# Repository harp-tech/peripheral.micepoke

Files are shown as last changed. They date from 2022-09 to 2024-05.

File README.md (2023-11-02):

# Peripheral - Mice Poke

## General description

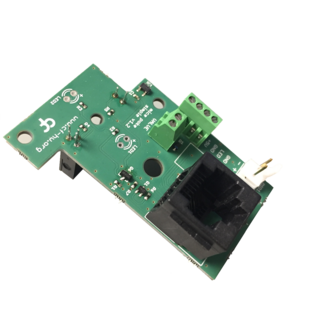
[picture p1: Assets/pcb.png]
"Mice Poke PCB"


----

[//]: # (Tables can be generated using: https://www.tablesgenerator.com/markdown_tables)

## Hardware compatibility

| Peripheral HW Version 	| Board 	 | Board HW Version 	| Notes 	|
|---	|---	 |---	|---	|
| **1.3** | [Device.Behavior](https://github.com/harp-tech/device.behavior) 	| > 1.0 | 	|
| **1.2** | [Device.Behavior](https://github.com/harp-tech/device.behavior) | > 1.0 | 	|
| 	| 	 | 	| 	|
----

## Key Features

* Poke detection through an infrared beam
* Control of 2 LEDs + an external LED
* 12V valve control when connected to an Harp Behavior

----

## Connectivity [v1.3]

* 1x 12V Valve [screw terminal]  
* 1x DIO, IR LED, IR Photodiode, LED, 5V, GND  [screw terminal] 

----

## Licensing

License files can be found, and are applied to, each individual subfolder in this repository.

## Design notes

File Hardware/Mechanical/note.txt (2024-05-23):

Version 1.2 has an height offset of 0.5 mm.
Version 1.3 is equivalent to v1.2 without small holes in the LEDs orifices

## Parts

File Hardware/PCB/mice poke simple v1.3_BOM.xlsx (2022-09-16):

Part(s) | Quantity | Description | Distributor | Part. No.
IC1 | 1 | SingleBuffer / Driver, Inverting, 3-State, 1.65V to 5.5V, SOT-23-5 | Farnell | 1741039
U1 | 1 | Photointerrupter | Mouser | 852-GP1A57HRJ00F
Q1 | 1 | TRANSISTOR,NPN,45V,0.5A | Farnell | 1843701
Q2 | 1 | Transistor, P Channel, -1.5 A, -20 V, 75 mohm, -4.5 V, -600 mV | Farnell | 1858672
R1 | 1 | RES SMD 0402 150ohm, ± 1% | Farnell | 2331461
R2, R3 | 2 | RES SMD 0402 300ohm, ± 1% | Farnell | 2140722
R5 | 1 | RES SMD 0402 510ohm, ± 1% | Farnell | 2302602
R4 | 1 | RES SMD 0402 3300ohm, ± 1% | Farnell | 2140818
R6, R7 | 2 | RES SMD 0402 10kohm, ± 5% | Farnell | 2059239
C1 | 1 | CAP CER 100NF 10V X5R 0402 | Farnell | 2310530
C2 | 1 | CAP CER 10nF 50V ±10% X7R 0402 | Mouser | 81-GCM155R71H103KA5D
D1 | 1 | DIODE SCHOTTKY 30V 1A SOD323 | Farnell | 2432677
LED1, LED2 | 2 | LED, White, Through Hole, T-1 (3mm), 20 mA, 3.2 V, 7.15 cd | Farnell | 2682714
VALVE | 1 | Terminal Block, 2.54 mm, 2 Ways, 30 AWG, 16 AWG, 1.4 mm² | Farnell | 282834-2
J1 | 1 | JACK, MODULAR, TOP ENTRY, 8/8 | Farnell | 1214653
X1 | 1 | Blocos de terminais fixos 8P SIDE ENTRY 2.54mm | Mouser | 571-282834-8
Components | 19
Licensed under the TAPR Open Hardware License (www.tapr.org/OHL)
Copyright 2016-2019 Artur Silva and Filipe Carvalho

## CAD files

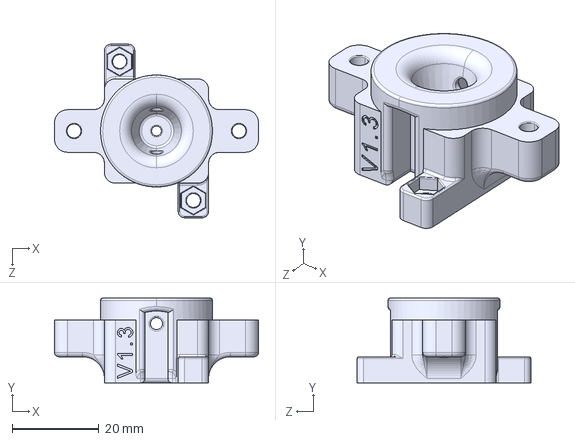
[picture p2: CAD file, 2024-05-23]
Hardware/Mechanical/Mouse_Poke_Round_V1_3.STEP
47.0 x 19.5 x 40.0 mm

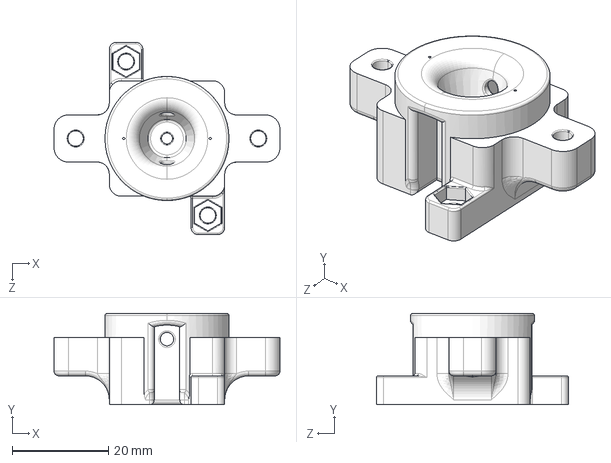
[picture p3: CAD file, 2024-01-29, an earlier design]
Hardware/Mechanical/Mouse_Poke_Round_V1.STEP
47.0 x 19.0 x 40.0 mm

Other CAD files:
Hardware/Mechanical/Mouse_Poke_Round_V1_2.STEP
Hardware/Mechanical/Mouse_Poke_Round_V1.STL
Hardware/Mechanical/Mouse_Poke_Round_V1_2.STL
Hardware/Mechanical/Mouse_Poke_Round_V1_3.STL

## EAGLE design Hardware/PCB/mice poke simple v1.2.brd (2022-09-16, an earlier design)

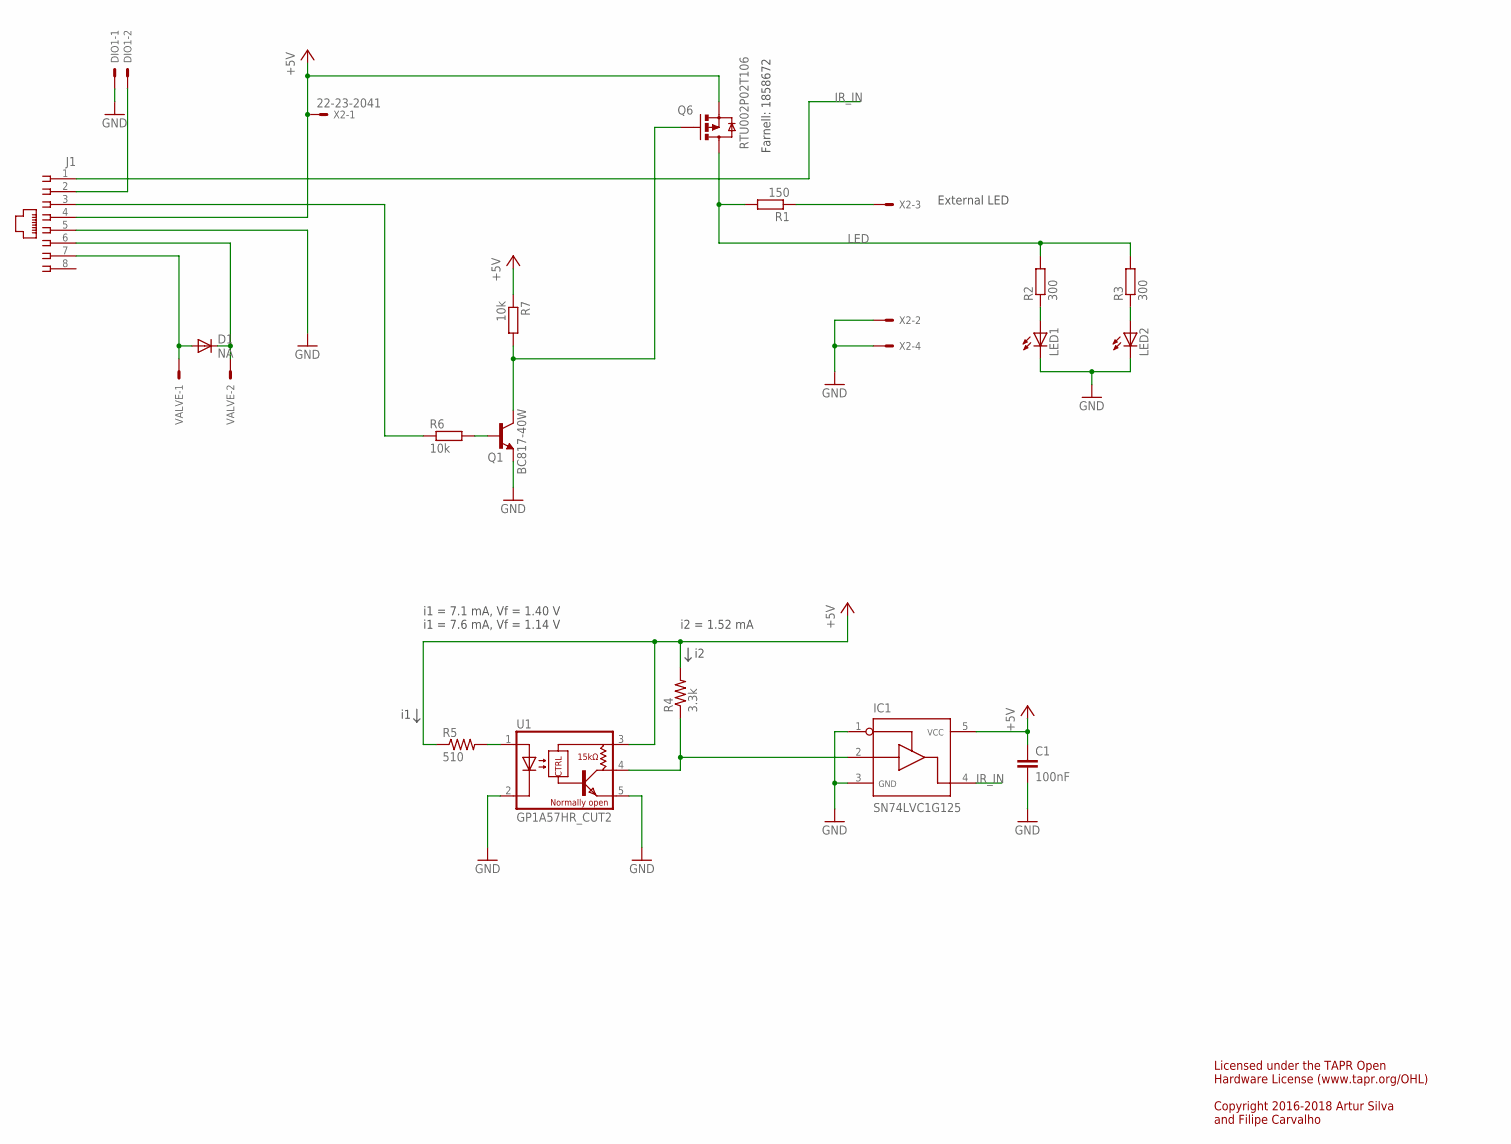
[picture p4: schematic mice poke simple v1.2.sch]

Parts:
C1: 100nF; C0402
D1: NA; SOD323-R
DIO1: 22-23-2021
IC1: SN74LVC1G125; SOT23-5
J1: 215878-2
LED1, LED2: LED3MM
Q1: BC817-40W; SOT323-BEC
Q6: RTU002P02T106; SOT323
R1: 150; R0402
R2, R3: 300; R0402
R4: 3.3k; R0402
R5: 510; R0402
R6, R7: 10k; R0402
U1: GP1A57HR_CUT2
VALVE: 22-23-2021
X2: 22-23-2041

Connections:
+5V: C1.1, IC1.5, J1.4, Q6.1 (S), R4.2, R5.1, R7.1, U1.3 (VCC), X2.1
GND: C1.2, DIO1.1, IC1.1, IC1.3, J1.5, LED1.K (C), LED2.K (C), Q1.E, U1.2 (C), U1.5 (GND), X2.2, X2.4
IR_IN: IC1.4, J1.1
LED: Q6.3 (D), R1.2, R2.2, R3.2
unnamed: R1.1, X2.3
unnamed: R5.2, U1.1 (A)
unnamed: D1.A, J1.7, VALVE.1
unnamed: D1.C, J1.6, VALVE.2
unnamed: DIO1.2, J1.2
unnamed: J1.3, R6.1
unnamed: IC1.2, R4.1, U1.4 (VO)
unnamed: LED2.A, R3.1
unnamed: LED1.A, R2.1
unnamed: Q1.C, Q6.2 (G), R7.2
unnamed: Q1.B, R6.2

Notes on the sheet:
i1 = 7.1 mA, Vf = 1.40 V i1 = 7.6 mA, Vf = 1.14 V
i2 = 1.52 mA
External LED
Farnell: 1858672
Licensed under the TAPR Open Hardware License (www.tapr.org/OHL) Copyright 2016-2018 Artur Silva and Filipe Carvalho

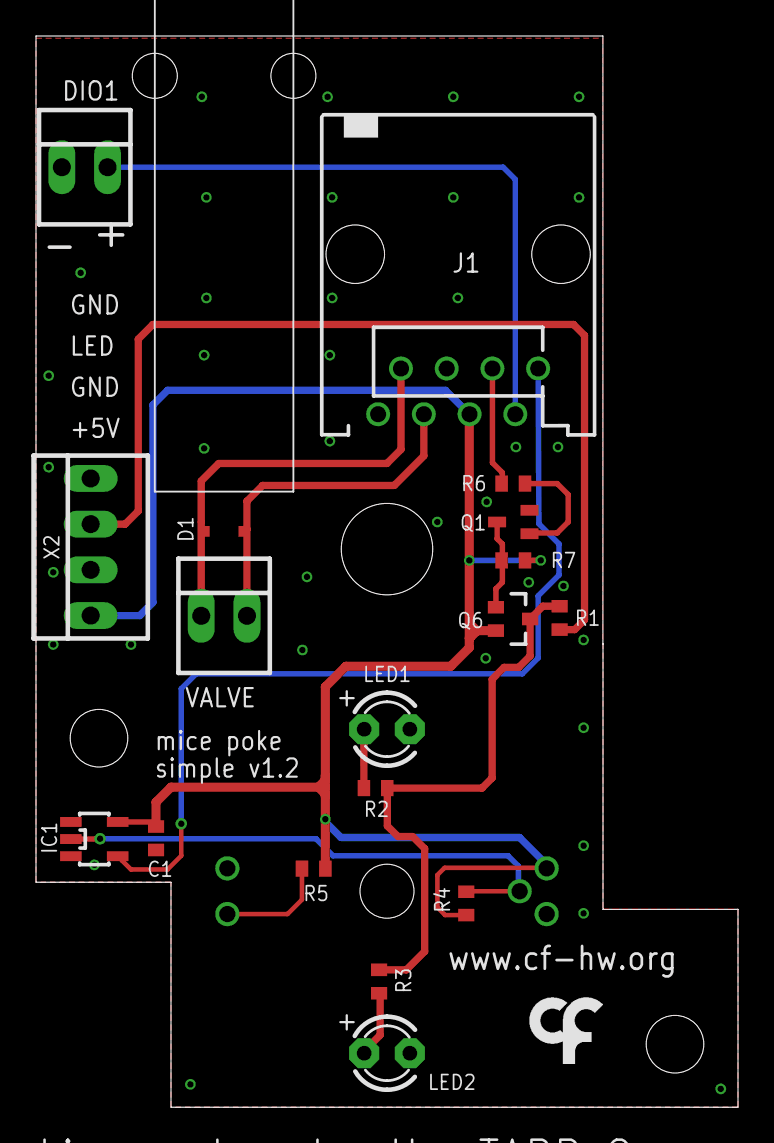
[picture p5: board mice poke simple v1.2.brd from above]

Board: 2 copper layers, 39.0 x 59.5 mm, 20 parts (1 on the bottom side), 15 nets.

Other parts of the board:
U$2: LOGO_7

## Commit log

2022-09-16 Organize folders and add peripheral boards
    [mice poke simple v1.2.brd, mice poke simple v1.2.sch, mice poke simple v1.2_BOM.xlsx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]
2022-12-13 Move design files to PCB folder
    [mice poke simple v1.2.brd, mice poke simple v1.2.sch, mice poke simple v1.2_BOM.xlsx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]
2022-12-13 Change folder name
    [Mouse_Poke_Round_V1.STL, Mouse_Poke_Round_V1_2.STL]
2022-12-15 Move PCB license to subfolder
2022-12-23 refactor repository structure
    [Mouse_Poke_Round_V1.STL, Mouse_Poke_Round_V1_2.STL, mice poke simple v1.2.brd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]
2023-11-01 Add pcb image
2024-01-29 add STEP files for pokes
    [Mouse_Poke_Round_V1.STEP, Mouse_Poke_Round_V1_2.STEP]
2024-05-23 Add poke version 1.3
    [Mouse_Poke_Round_V1_3.STEP, Mouse_Poke_Round_V1_3.STL]
2026-04-24 Updated valve footprint and increased resistors.
